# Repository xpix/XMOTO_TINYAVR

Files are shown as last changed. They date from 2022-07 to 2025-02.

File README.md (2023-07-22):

# Documentation for Motor Controller with PID Control to use a DC motor as stepper/servo

This code is designed for a motor controller and has merged the PID code of Josh Kopel with the code of the Makerbot servo-controller board. This code can be used on some boards by changing some values.

## Hardware Requirements

- motor controller as H-Bridge
- Hall Sensor PCB
- Ramps 1.4 stepper driver

## Software Requirements

- PID_v2.h library
- EEPROM.h library

## Code Explanation

### Motor Driver Type

The type of motor driver is defined using the `PWMCONTROL` variable. If `PWMCONTROL` is set to `1`, it means that the motor driver has only a PWM interface. In this case, the minimum and maximum values for PWM to turn the motor are defined using `PWMMIN` and `PWMMAX`.

### Pin Definitions

The pins used in the code are defined as follows:

- `encoder0PinA` and `encoder0PinB`: Pins for the Hall Sensor PCB
- `MotorIN1` and `MotorIN2`: Pins for the motor driver (if `PWMCONTROL` is set to `1`)
- `MotorDIR` and `MotorPWM`: Pins for the motor driver (if `PWMCONTROL` is set to `0`)
- `STEP_PIN` and `DIR_PIN`: Pins for the Ramps 1.4 stepper driver
- `EnableLED`: Pin for the LED that signals if the MCU is running

### PID Values

The default PID values are defined using the `MyObject` struct. The `kp`, `ki`, and `kd` values are set to `7.00`, `0.04`, and `0.20` respectively. These values can be changed by the user.

### Setup Function

In the `setup()` function, the following tasks are performed:

- Serial communication is started at a baud rate of 9600.
- The saved PID values are retrieved from the EEPROM. If no values are saved, the default values are used.
- The pins are set to their respective modes.
- Interrupts are attached to the `encoder0PinA` and `STEP_PIN` pins.
- The PID is set to automatic mode with a sample time of 2 and an output limit of -255 to 255.

### Loop Function

In the `loop()` function, the following tasks are performed:

- The set

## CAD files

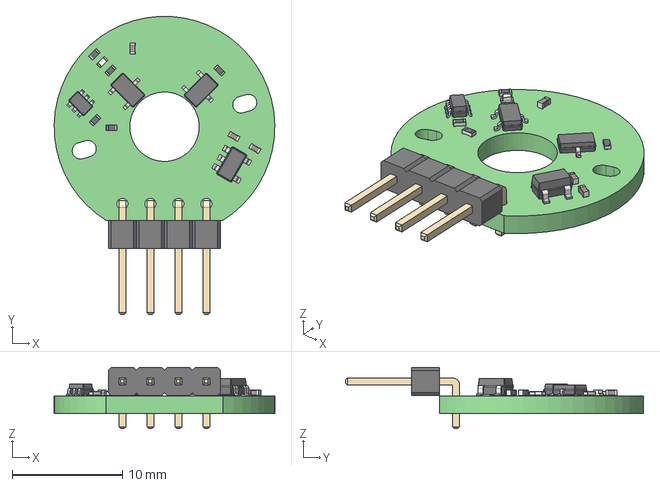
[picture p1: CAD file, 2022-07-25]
Hardware/asmartcap_xMoto.step
20.0 x 27.0 x 5.54 mm
asmartcap_xMoto PCB

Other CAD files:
Hardware/asmartcap_xMoto v1.dxf

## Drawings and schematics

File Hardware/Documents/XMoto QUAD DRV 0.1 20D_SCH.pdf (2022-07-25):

## XMOTO20D 2 Hall Sensors STM and PWR

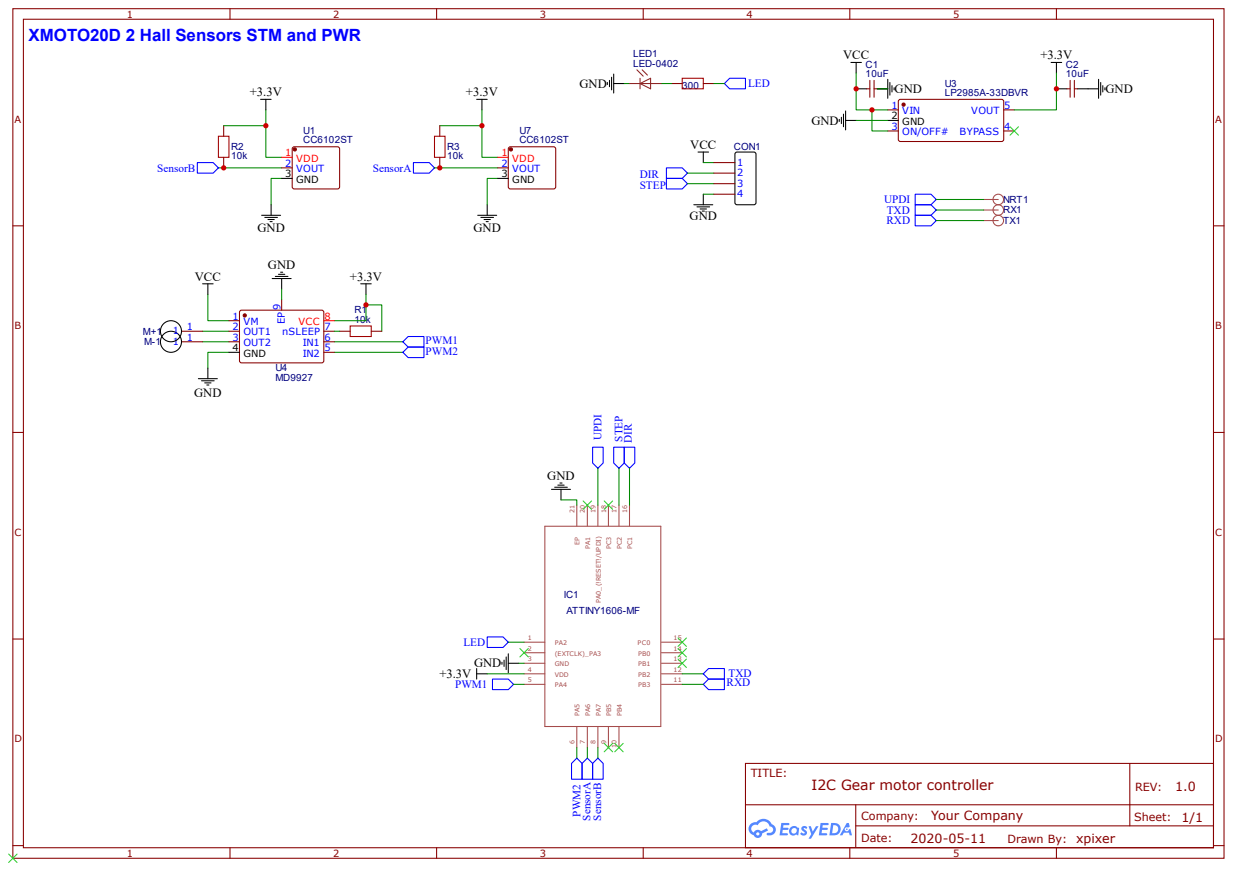
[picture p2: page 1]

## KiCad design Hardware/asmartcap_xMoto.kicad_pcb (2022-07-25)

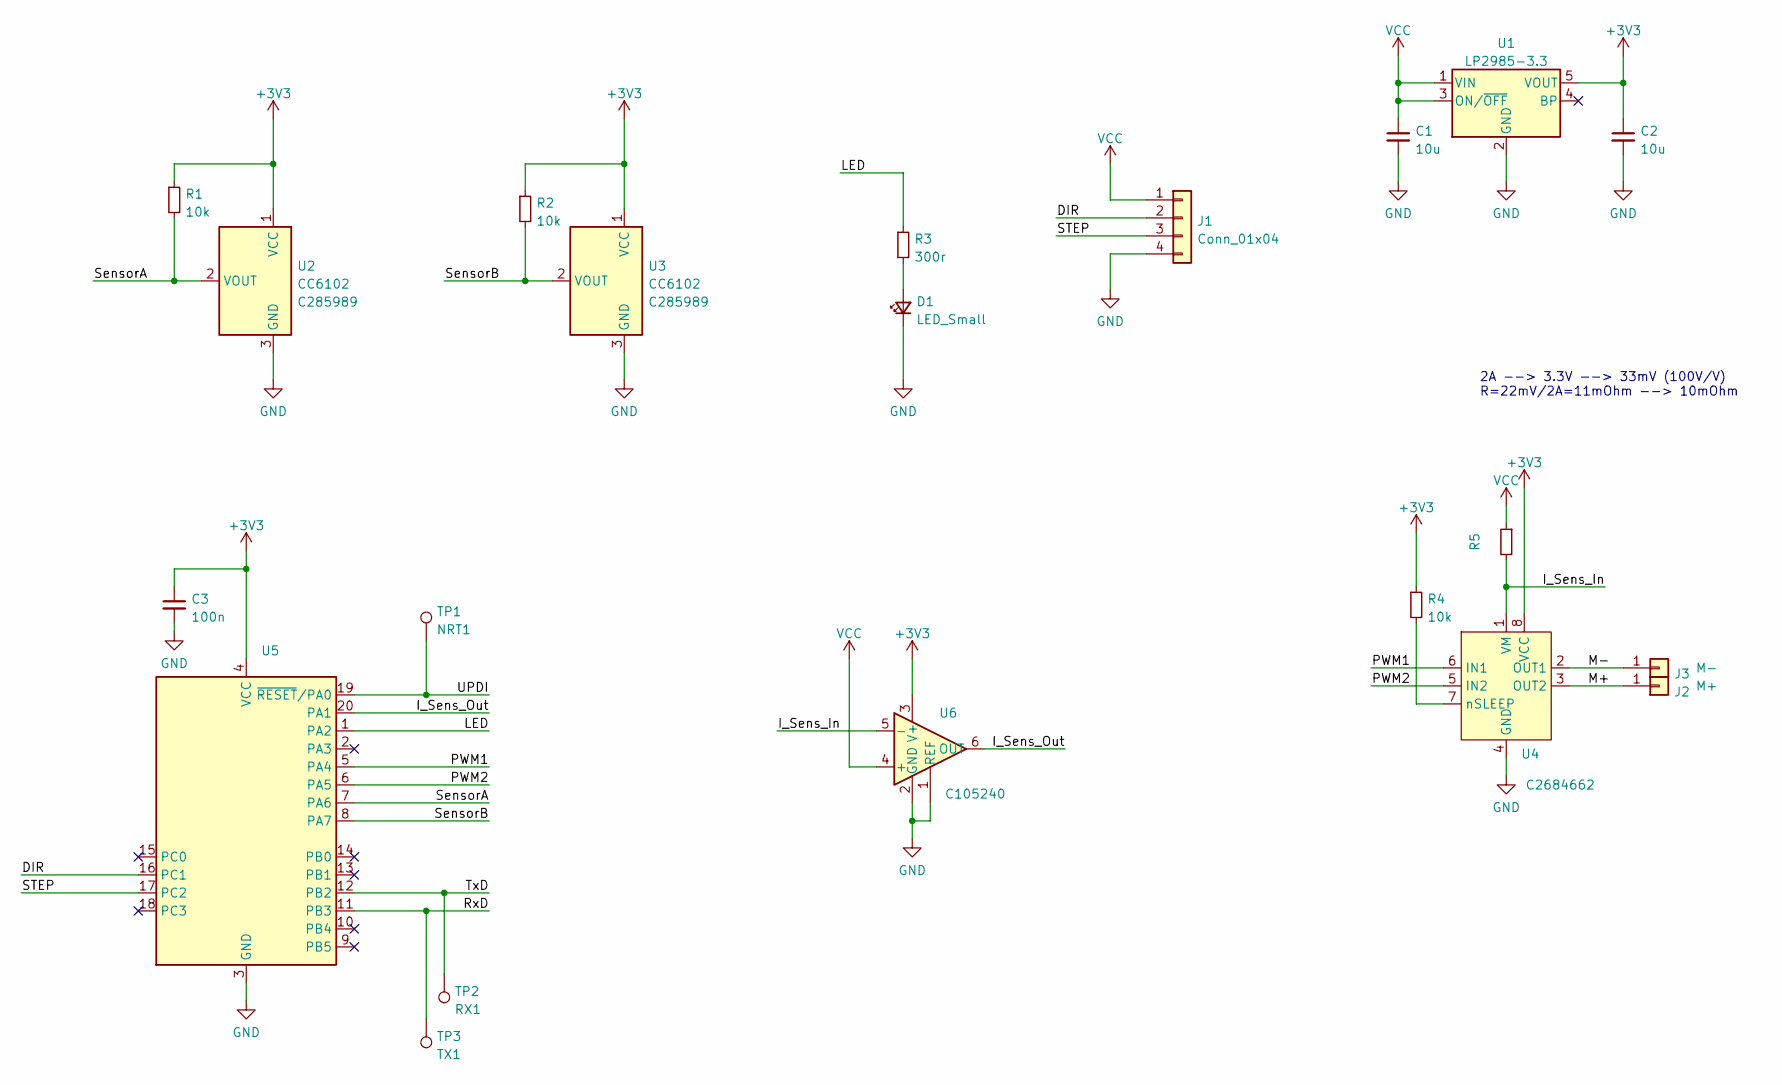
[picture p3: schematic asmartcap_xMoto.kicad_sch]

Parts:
C1, C2: 10u; C_0402_1005Metric; LCSC C15525
C3: 100n; C_0402_1005Metric
D1: LED_Small; LED_0402_1005Metric
J1: Conn_01x04; PinHeader_1x04_P2.54mm_Horizontal
J2: M+; TestPoint_Plated_Hole_D3.0mm
J3: M-; TestPoint_Plated_Hole_D3.0mm
R1, R2, R4: 10k; R_0402_1005Metric; MPN 0402WGF3000TCE; LCSC C25102
R3: 300r; R_0402_1005Metric
R5: MPN RTT03R010FTP; JLCPCB C158899
TP1: NRT1; TestPoint_Pad_D1.5mm
TP2: RX1; TestPoint_Pad_D1.5mm
TP3: TX1; TestPoint_Pad_D1.5mm
U1: LP2985-3.3; SOT-23-5
U2, U3: CC6102; TSOT-23; LCSC C285989
U4: LCSC C2684662
U5: (no value)
U6: JLCPCB C105240

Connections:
+3V3: C2.1, C3.1, R1.1, R2.1, R4.1, U1.5 (VOUT), U2.1 (VCC), U3.1 (VCC), U4.8 (VCC), U5.4 (VCC), U6.3 (V+)
/DIR: J1.2, U5.16 (PC1)
/I_Sens_In: R5.2, U4.1 (VM), U6.5 (-)
/I_Sens_Out: U5.20 (PA1), U6.6 (OUT)
/LED: R3.1, U5.1 (PA2)
/M+: J2.1, U4.3 (OUT2)
/M-: J3.1, U4.2 (OUT1)
/PWM1: U4.6 (IN1), U5.5 (PA4)
/PWM2: U4.5 (IN2), U5.6 (PA5)
/RxD: TP3.1, U5.11 (PB3)
/STEP: J1.3, U5.17 (PC2)
/SensorA: R1.2, U2.2 (VOUT), U5.7 (PA6)
/SensorB: R2.2, U3.2 (VOUT), U5.8 (PA7)
/TxD: TP2.1, U5.12 (PB2)
/UPDI: TP1.1, U5.19 (~RESET/PA0)
GND: C1.2, C2.2, C3.2, D1.1 (K), J1.4, U1.2 (GND), U2.3 (GND), U3.3 (GND), U4.4 (GND), U4.9 (Pad), U5.3 (GND), U5.21 (GND), U6.1 (REF), U6.2 (GND)
unnamed: D1.2 (A), R3.2
unnamed: R4.2, U4.7 (nSLEEP)
VCC: C1.1, J1.1, R5.1, U1.1 (VIN), U1.3 (ON/~OFF), U6.4 (+)

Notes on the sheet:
2A --> 3.3V --> 33mV (100V/V) R=22mV/2A=11mOhm --> 10mOhm

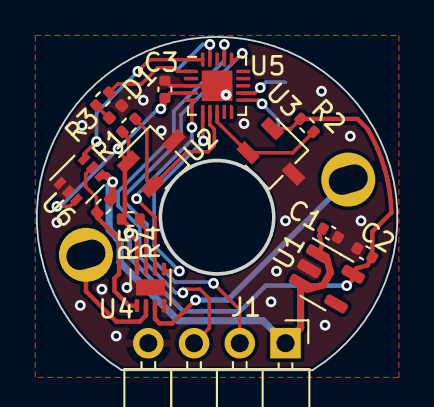
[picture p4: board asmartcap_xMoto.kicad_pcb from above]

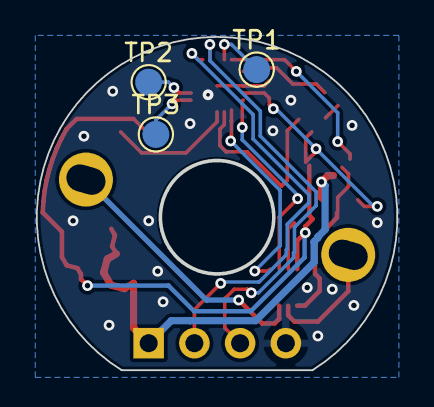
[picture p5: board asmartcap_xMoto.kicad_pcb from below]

Board: 2 copper layers, 20.0 x 18.5 mm, 21 parts (3 on the bottom side), 19 nets.

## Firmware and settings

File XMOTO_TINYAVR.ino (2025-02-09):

/* 

i have made this code for the LMD18245 motor controller, 
i have merged the pid code of  Josh Kopel 
whith the code of makerbot servo-controller board,
you can use this code on the some board changing some values.
Daniele Poddighe

https://github.com/sebleedelisle/freeservo/tree/master/ServoStrap-master

Changes from Frank Herrmann for XMOTO and XMOTOD20

*/ 

#include <PID_v2.h>
#include <EEPROM.h>

#if defined(MILLIS_USE_TIMERA0)||defined(__AVR_ATtinyxy2__)
  #error "This sketch takes over TCA0, don't use for millis here.  Pin mappings on 8-pin parts are different"
#endif

// Type of Motordriver as is, with just an PWM Interface = true
// DRV8803
#define PWMCONTROL        1
#define PWMMIN           90 // minimum value for PWM to turn the motor
#define PWMMAX          200 // maximum value for PWM

#define EEPIDADDR         1 // Adress for saved PID Values

// Connect to Hall Sensor PCB
#define encoder0PinA  	2 // PA6
#define encoder0PinB  	3 // PA7

// If u need an revert, please change here the pins to motorcontroller
#if PWMCONTROL
  #define MotorIN1        1 // PA4
  #define MotorIN2        0 // PA5
#else
  #define MotorDIR    	  0 // PA4
  #define MotorPWM 		    1 // PA5
#endif

//from ramps 1.4 stepper driver
#define STEP_PIN	      12 // PC2
#define DIR_PIN         11 // PC1
#define EnableLED       15 // PB6


volatile long encoder0Pos = 0;

long GetSteps = 0;

// PID default values 
struct MyObject {
  double kp;
  double ki;
  double kd;
};
MyObject PIDvals = {
  1.35, 0.00, 0.01 // defaut values for PID
};

double input = 0, output = 0, setpoint = 0, error = 0;
PID myPID(&input, &output, &setpoint, PIDvals.kp, PIDvals.ki, PIDvals.kd, DIRECT);  

long LastInterval = 0;
long previousMillis = 0;        // will store last time LED was updated
bool dir     = false;

// ---------------------- SETUP -----------------------
void setup() { 
	Serial.begin(9600);

  pinMode(EnableLED, OUTPUT);
  digitalWrite (EnableLED, HIGH);

  // get Saved (EEPROM) or default PID Values
  MyObject PIDv;
  EEPROM.get(EEPIDADDR, PIDv);
  if(not (PIDv.kp > 0.01)){
     PIDv = {
        PIDvals.kp, PIDvals.ki, PIDvals.kd // defaut values
     };
  }
  myPID.SetTunings(PIDv.kp, PIDv.ki, PIDv.kd);
  Serial.println("Saved (EEPROM) or default PID Values:");
  Serial.println(PIDv.kp);
  Serial.println(PIDv.ki);
  Serial.println(PIDv.kd);

  myPID.SetMode(AUTOMATIC);     //set PID in Auto mode
  myPID.SetSampleTime(2);     // refresh rate of PID controller
  myPID.SetOutputLimits(-255, 255); // this is the MAX PWM value to move motor

	// Set Pins 
	pinMode(encoder0PinA, INPUT); 
	pinMode(encoder0PinB, INPUT);  

#if PWMCONTROL
  pinMode(MotorIN1, OUTPUT); 
  pinMode(MotorIN2, OUTPUT);
#else
	pinMode(MotorDIR, OUTPUT); 
	pinMode(MotorPWM, OUTPUT);
#endif


	//motor control Pins
	pinMode(STEP_PIN, INPUT_PULLUP);
	pinMode(DIR_PIN, INPUT);

	// Interupts for position and target steps 
	attachInterrupt(digitalPinToInterrupt(encoder0PinA), doEncoderMotor0, CHANGE);  // encoderA pin on interrupt
	attachInterrupt(digitalPinToInterrupt(STEP_PIN), 	   countStep, 	    RISING);  // interrupt to count steppules

	Serial.println("start");
	Serial.println("Position ToPosition MotorPWM RealPWM");

  delay(2000);
  digitalWrite (EnableLED, LOW);
} 

// ---------------------- LOOP -----------------------
void loop(){

  byte n = Serial.available();
  if (n != 0) {
    MyObject PIDv;
    PIDv.kp = Serial.parseFloat();
    PIDv.ki = Serial.parseFloat();
    PIDv.kd = Serial.parseFloat();

    // write only PID values in eeprom if not rubbish
    if( PIDv.kp > 0.00 && PIDv.ki > 0.00 && PIDv.kd > 0.00){
      MyObject PIDvals = {
        PIDv.kp, PIDv.ki, PIDv.kd // defaut values
      };
      Serial.println("Input PID values saved in eeprom:");
      EEPROM.put(EEPIDADDR, PIDvals);
  
      myPID.SetTunings(PIDv.kp, PIDv.ki, PIDv.kd);
    }

    // control PID values    
    Serial.println(PIDv.kp);
    Serial.println(PIDv.ki);
    Serial.println(PIDv.kd);
  }

	setpoint = GetSteps; // setpoint to Steps get from controller
	input = encoder0Pos; // real Position
  error = abs(setpoint - input);
  myPID.Compute();   // compute correct value
  int realpwm=0;
  if(error){
    realpwm = pwmOut(output);    // get PWM Value from PID calculated
  }
  else {
    realpwm = pwmOut(0);    // break
  }

  // Diganostic via serialplotter from arduino ide
  // Serial.println("Position ToPosition MotorPWM DIR");
  if(millis() - LastInterval > (abs(error) > 10 ? 100 : 1000)){

    if(output < PWMMIN){
      digitalWrite (EnableLED, HIGH); // signal that mcu is running
    }

    Serial.print(input);
    Serial.print(" ");
    Serial.print(setpoint);
    Serial.print(" ");
    Serial.print(output);
    Serial.print(" ");
    Serial.print(realpwm);
    Serial.println("");

    if(output < PWMMIN){
      digitalWrite (EnableLED, LOW);
    }
    LastInterval=millis();
  }
}

// ---------------------- SUBS -----------------------
#if PWMCONTROL
int pwmOut(int out) {
  int pwm = 0;
  if (out > 0) {
    // forward
    pwm = map(out, 0, 255, PWMMIN, PWMMAX );
    analogWrite ( MotorIN1, pwm );       
    digitalWrite ( MotorIN2, LOW );
  }
  else if (out < 0) {
    // reverse
    pwm = map(abs(out), 0, 255, PWMMIN, PWMMAX );
    digitalWrite ( MotorIN1, LOW );    // if REV < encoderValue motor move in reverse direction.   
    analogWrite ( MotorIN2, pwm );                      
  }
  else {
    // break
    digitalWrite ( MotorIN1, LOW );
    digitalWrite ( MotorIN2, LOW );
  }
  return pwm;
}
#else
void pwmOut(int out) {                               
	if (out > 0) {
		analogWrite( MotorPWM, out );      	
		digitalWrite ( MotorDIR ,LOW );
	}
	else {
		analogWrite( MotorPWM, abs(out) );                      
		digitalWrite ( MotorDIR, HIGH );		// if REV < encoderValue motor move in reverse direction.   
  }
}
#endif

void doEncoderMotor0(){
	if (digitalRead(encoder0PinA) == HIGH) {   // found a low-to-high on channel A
		if (digitalRead(encoder0PinB) == LOW) {  // check channel B to see which way
												 // encoder is turning
			encoder0Pos = encoder0Pos - 1;         // CCW
		} 
		else {
			encoder0Pos = encoder0Pos + 1;         // CW
		}
	}
	else                                        // found a high-to-low on channel A
	{ 
		if (digitalRead(encoder0PinB) == LOW) {   // check channel B to see which way
												  // encoder is turning  
			encoder0Pos = encoder0Pos + 1;          // CW
		} 
		else {
			encoder0Pos = encoder0Pos - 1;          // CCW
		}
	}
}

void countStep(){
	dir = digitalRead(DIR_PIN);
	if(dir == HIGH){
	  GetSteps++;
	}
	else{
	  GetSteps--;
	}
}

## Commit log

2022-07-25 initial version of XMOTO20D soft and ga
    [asmartcap_xMoto v1.dxf, asmartcap_xMoto.kicad_pcb, asmartcap_xMoto.kicad_sch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]
2023-07-22 fix PID write and get values from eeprom
    [XMOTO_TINYAVR.ino]
2025-02-09 change some values and PID values
